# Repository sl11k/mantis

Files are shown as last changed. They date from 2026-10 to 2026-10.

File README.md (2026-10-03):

# MANTIS

**Multimodal Autonomous Non-Invasive Technical Inspection System.** MANTIS is a portable device that
sticks to a machine with magnets. It measures vibration, sound and temperature without touching the
machine's internals, and streams the results live to a phone or computer over Bluetooth LE.

**Live dashboard:** https://sl11k.github.io/mantis/

<p>
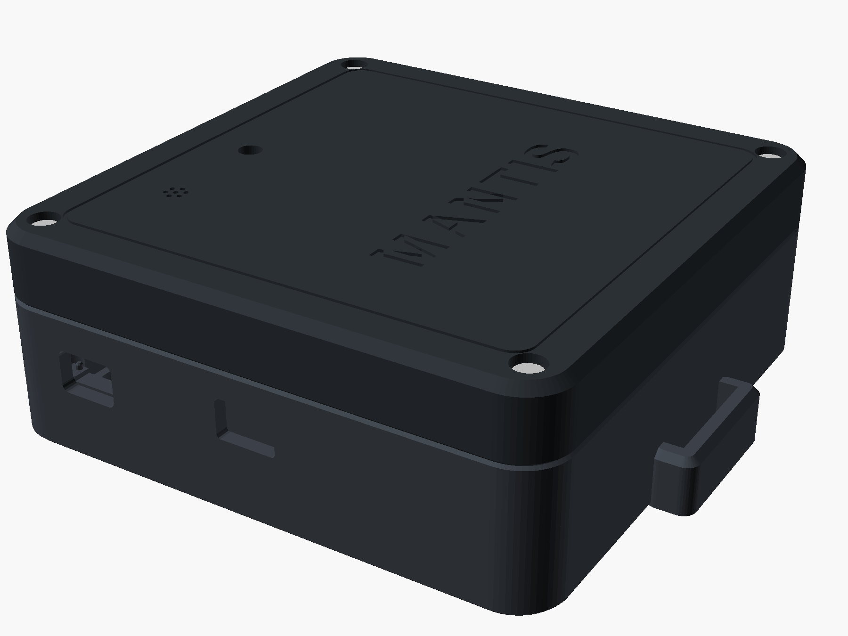
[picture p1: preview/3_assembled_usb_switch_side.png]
Assembled enclosure, USB and switch side
  
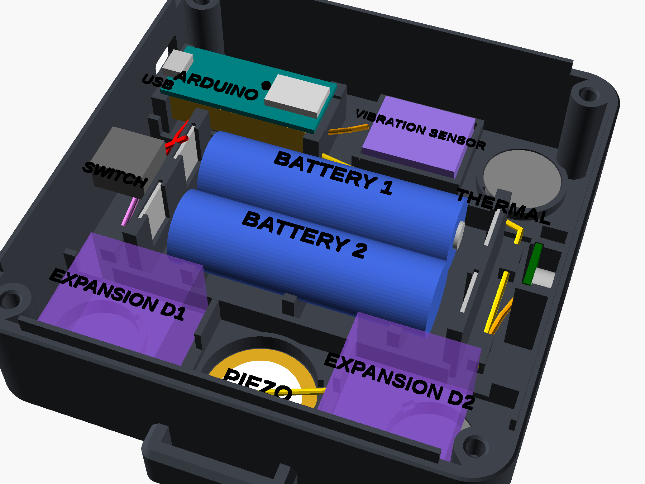
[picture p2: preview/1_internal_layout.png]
Internal layout: Arduino, 2x18650 cells, piezo, IR and vibration sensor bays
  
</p>

| Folder | Contents |
|---|---|
| [`app/`](app/) | Web dashboard (Web Bluetooth / Web Serial). It is deployed to GitHub Pages on every push |
| [`firmware/MANTIS/`](firmware/MANTIS/) | Arduino firmware |
| [`mantis_enclosure.scad`](mantis_enclosure.scad) | Parametric OpenSCAD enclosure (FDM) |
| [`stl/`](stl/) | Ready-to-print top and bottom shells |
| [`preview/`](preview/) | Renders: internal layout, exploded view, sides, machine face, section |

## What it measures

Every ~1.1 s:

- **Vibration.** The LSM9DS1 accelerometer samples at ~930 Hz and each axis gets a 1024-point FFT. From that the device reports:
  - velocity RMS over 10–475 Hz, with the **ISO 10816** zone (A good, B acceptable, C needs attention, D danger) for machine classes I–IV
  - acceleration RMS and peak
  - the dominant frequency
  - a 64-band velocity spectrum
- **Sound.** A-weighted sound level in dB(A) from the on-board PDM microphone. The calibration comes from the datasheets and is approximate (±3 dB); `MIC_CAL_DB` trims it against a reference meter.
- **Inside the enclosure.** Temperature and humidity (HTS221) and pressure (LPS22HB).
- **Surface temperature** (optional). An MLX90614 IR thermometer looks through the side window and is detected automatically when plugged in.
- **Contact / impacts** (optional). A piezo disc on the machine face.

## Hardware

| Part | Notes |
|---|---|
| Arduino Nano 33 BLE Sense **Rev1** | IMU, environmental sensors, microphone and BLE on board |
| MLX90614 / GY-906 IR module (optional) | I²C on A4 (SDA) / A5 (SCL), address 0x5A |
| Piezo disc, 27 mm (optional) | Analog input A0. Set `PIEZO_ENABLED = true` in the firmware |
| 2 × 18650 cells + spring/plate contacts | 2S into VIN through the power switch |
| KCD11 mini rocker (13 × 8.5 mm) or small slide switch | Left wall |
| 4 × Ø20 × 5 mm magnets | Glued into pockets from the inside, 0.8 mm skin to the machine face |
| 4 × M3 × 16 screws + M3 heat-set inserts | Or self-tapping: set `boss_hole_diameter = 2.5` |
| 5 mm LED or light pipe, Ø10 mm rubber pads, 25 mm hook-and-loop strap | Optional |

## Firmware

1. Install the Arduino IDE. In Boards Manager, add **Arduino Mbed OS Nano Boards** (tested with 4.6.0). In Library Manager, add **ArduinoBLE** (tested with 2.1.0). `PDM` and `Wire` come with the board package.
2. Open `firmware/MANTIS/MANTIS.ino`, choose **Arduino Nano 33 BLE** and the board's port, then upload.
3. Settings are at the top of the file: `PIEZO_ENABLED`, `PIEZO_PIN`, `PIEZO_IMPACT_MV`, the default `isoClass`, and `MIC_CAL_DB`.

Outputs:

- **BLE:** advertises as `MANTIS`, service `4d414e54-4953-4e53-5045-435400000000`. The full packet layout is documented in the header of `MANTIS.ino`.
- **USB serial (115200):** one JSON line per measurement window. Lines starting with `#` are human-readable.
- **Commands:** over USB, `C1`…`C4` set the ISO class, `I` blinks the LED, and `M` dumps 4096 raw microphone samples for diagnostics. The same commands go over BLE through the control characteristic.
- **On-board LED:** shows the zone colour. It blinks while waiting for a connection and stays solid once connected. Blue means no data yet.

## Enclosure

The enclosure is 120 × 120 × 45 mm and split at 30 mm. It is fully parametric. Open the file in
OpenSCAD and set `view_mode` to `"bottom"` or `"top"`, then press F6 and export to STL. The `stl/` folder
already contains both shells at the default settings. Assert checks at the end of the file catch parts
that would collide.

The board dimensions in the file come from the Nano 33 BLE Sense **Rev2** datasheet. Rev1 has the same
footprint and mounting holes, but check the microphone port position (`mic_from_usb_end`) against your
board before printing the lid.

## Dashboard

Open https://sl11k.github.io/mantis/ in Chrome or Edge (desktop or Android), or in Bluefy on iPhone.
Then press **Connect Bluetooth** and pick **MANTIS**. It can be added to the home screen and works
offline after the first visit. For USB or local development, run `node app/serve.js` and open
http://localhost:8765. See [`app/README.md`](app/README.md).

Beyond the live view it is an inspection log: add each machine (name, location, ISO class, RPM),
record a steady 10–30 s measurement for it, and the app compares every measurement against that
machine's baseline, flags rises of 25 % or more, gives spectrum-based fault hints, and prints a PDF
report per machine or for the whole route. Data stays on the device; back it up from the Device tab.

After live data arrives, press **Create first reading** to save the next real measurement on this
browser. The completion summary remains after a page reload. Demo data cannot create it.

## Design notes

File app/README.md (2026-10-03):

# MANTIS dashboard

Inspection app for the MANTIS machine-inspection device (Arduino Nano 33 BLE Sense).
It shows vibration severity per ISO 10816 (zones A–D), the dominant frequency and the spectrum,
plus surface and internal temperature, humidity, pressure and sound level. The data arrives over
Bluetooth LE, or over USB on a computer.

Four sections (bottom bar on a phone, tabs on a computer):

| Section | What it does |
|---|---|
| **مباشر / Live** | Machine condition, the live sensor tiles, and **Record measurement**: pick the machine, hold the device on it, and a 10/15/30 s steady average is saved to that machine's log |
| **التحليل / Analysis** | Spectrum with 1×/2×/3× running-speed and 2× mains markers, rule-based fault hints (unbalance, misalignment, looseness, electrical, bearings), and the velocity trend |
| **المعدات / Machines** | Machine list sorted worst first, today's route progress, per-machine history against its baseline (first measurement, or any one you pick), PDF report and share |
| **الجهاز / Device** | Connection, device info, alerts, settings (language, theme, measurement length, 50/60 Hz mains, keep screen on, vibrate/sound alerts) and data backup |

Measurements stay in the browser on that phone or computer. Use **Device → Backup** now and then;
**Restore** merges a backup back in. Reports open the print dialog: choose *Save as PDF* to keep or send one.

**Open it:** https://sl11k.github.io/mantis/

| Device | How |
|---|---|
| Android | Chrome → **اتصال بلوتوث / Connect Bluetooth** → pick **MANTIS** |
| Windows / Mac / Linux | Chrome or Edge, same as above (USB also works) |
| iPhone / iPad | Safari has no Web Bluetooth, so open the link in the **Bluefy** browser (App Store) |

- **Install like an app:** browser menu → *Add to Home screen*. After the first visit it opens offline too.
- **No device at hand?** Press **عرض تجريبي / Demo** to see the dashboard with simulated data (demo measurements are tagged as such).
- **Run locally** (USB development): `node serve.js`, then open http://localhost:8765, or double-click `MANTIS.bat` on Windows.

Single static page, no build step and no dependencies. Arabic (RTL) by default, with English and dark mode.

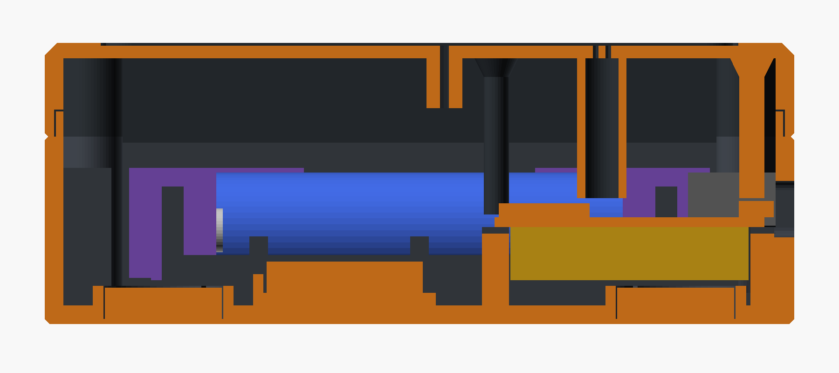
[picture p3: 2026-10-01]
preview/6_section_through_arduino.png

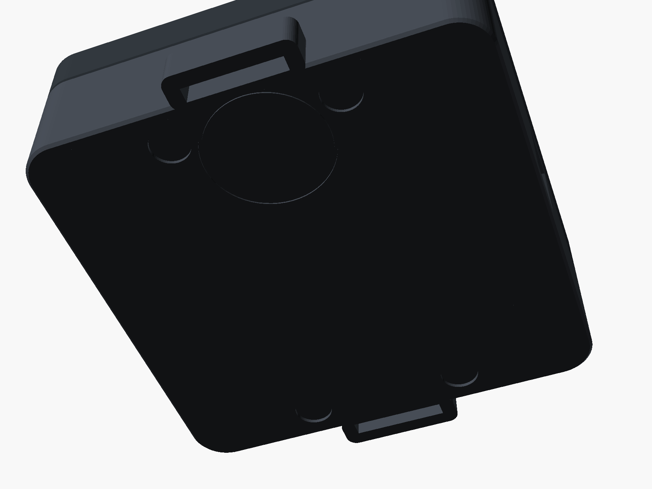
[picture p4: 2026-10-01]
preview/5_bottom_machine_face.png

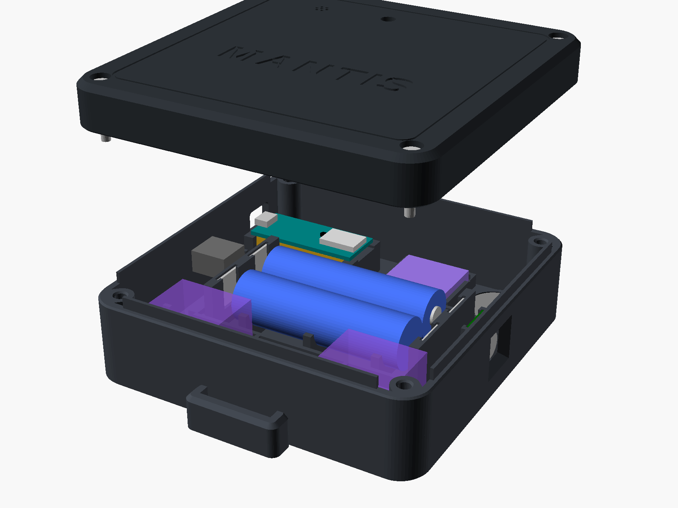
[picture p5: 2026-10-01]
preview/2_exploded.png

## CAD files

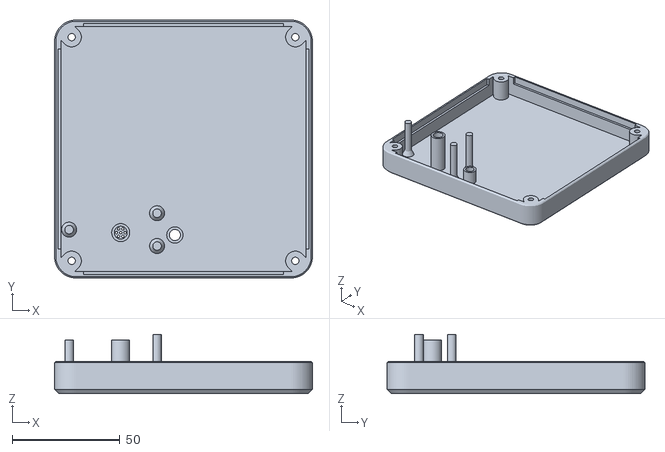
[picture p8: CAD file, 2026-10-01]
stl/MANTIS_top_shell.stl
120.0 x 120.0 x 27.5

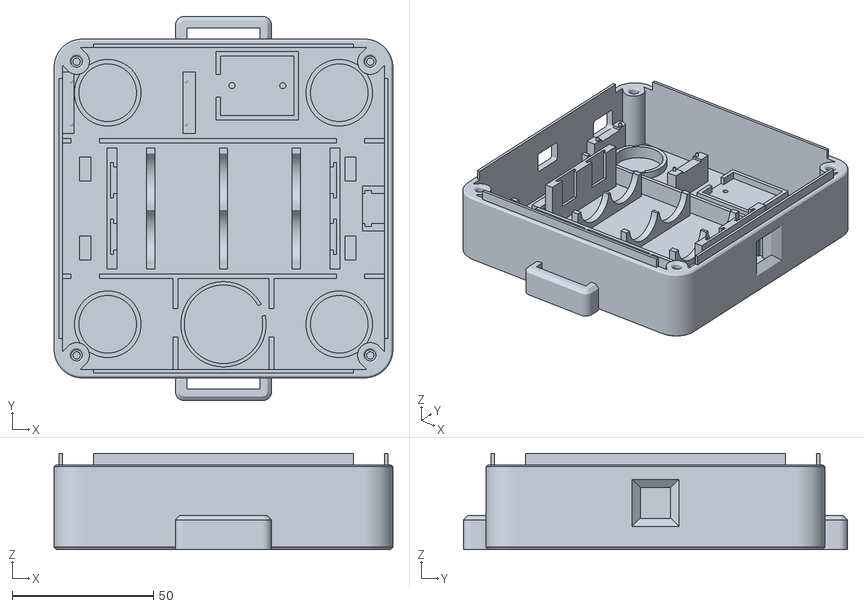
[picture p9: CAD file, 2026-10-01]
stl/MANTIS_bottom_shell.stl
120.0 x 136.0 x 34.0

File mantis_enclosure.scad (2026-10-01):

// ============================================================================
//  MANTIS - Multimodal Autonomous Non-Invasive Technical Inspection System
//  Portable inspection device  |  PARAMETRIC PROTOTYPE ENCLOSURE (FDM)
//  File: mantis_enclosure.scad          Rev B  2026-10-01
// ----------------------------------------------------------------------------
//  HOW TO USE
//    1. Set view_mode below (or use Window > Customizer).
//    2. view_mode = "bottom"  -> F6 -> File > Export > Export as STL
//       view_mode = "top"     -> F6 -> File > Export > Export as STL
//    3. Placeholders, labels and wire paths are NEVER generated in the
//       "top" / "bottom" modes, so they can never end up in a printed STL.
//
//  COORDINATES (assembled)          Z = 0 is the machine-contact face
//    -X = LEFT  wall  : USB access + power switch
//    +X = RIGHT wall  : IR thermal sensor window
//    -Y = FRONT wall,  +Y = BACK wall  (strap lugs on both)
//
//  ZONES (top view)
//    +Y  [ A: ARDUINO  (USB->left wall) ][ C2: VIBRATION POCKET ]
//        [ gutter |  B: 2 x 18650 POWER (along X) | gutter+C3 IR ]
//    -Y  [ D1: EXPANSION ][ C1: PIEZO (floor) ][ D2: EXPANSION ]
//  All dimensions in mm.
// ============================================================================

/* [View] */
// What to show / export
view_mode = "assembled"; // [assembled, top, bottom, exploded, internal_layout, section]
// "top" mode: flip the top shell roof-down (ready-to-print orientation)
print_orientation = true;
// Placeholder parts in assembled / exploded / section views
show_components = true;
show_labels = true;
show_wire_paths = true;
show_screws = true;
// Transparent ghost of the lid in internal_layout view
show_lid_ghost = false;
explode_gap = 45;
// Y position of the cut plane in "section" view (37.5 = through the Arduino)
section_y = 37.5;

/* [Enclosure] */
enclosure_width  = 120; // X  (100 is too small - see FIT CHECK at the end)
enclosure_length = 120; // Y
enclosure_height = 45;  // Z
wall_thickness   = 3.0;
floor_thickness  = 3.0;
roof_thickness   = 2.5;
corner_radius    = 10;
// Parting line height = bottom shell height (top shell = rest)
split_height     = 30;
top_edge_chamfer    = 2.0;
bottom_edge_chamfer = 0.8;
seam_chamfer        = 0.6;

/* [Tolerances] */
tolerance         = 0.4;  // general fit clearance
lip_clearance     = 0.25; // tongue -> lid rebate
battery_clearance = 0.5;  // added to the cell diameter
pcb_clearance     = 0.75; // keep-out around the Arduino PCB (each side)

/* [Shell joint and screws] */
lip_height    = 4;
lip_thickness = 1.2;              // lid keeps wall - lip - clearance = 1.55 mm
screw_diameter = 3;              // M3 (M2.5 possible: scale the values below)
screw_clearance_diameter = 3.4;
screw_head_diameter = 6.5;       // counterbore (M3 socket head = 5.5)
screw_head_depth = 4.5;          // counterbore depth -> M3 x 16 screws
screw_inset = 8;                 // screw axis distance from outer side faces
boss_diameter = 9;
// 4.0 = M3 heat-set insert (OD 4.2-4.6, L 5.7) | 2.5 = direct self-tapping M3
boss_hole_diameter = 4.0;
boss_hole_depth = 7;

/* [Magnets] */
magnet_diameter  = 20;
magnet_thickness = 5;
magnet_clearance = 0.4;  // on diameter - glue gap
magnet_skin      = 0.8;  // plastic between magnet and machine (4 layers @ 0.2)
magnet_cup_wall  = 1.6;
magnet_inset     = 19;   // magnet centre distance from outer side faces

/* [Battery] */
battery_option = "18650_cradle"; // [18650_cradle, pack_bay]
battery_diameter  = 18.5;
battery_length    = 65;
battery_end_space = 5;    // per end: spring / plate contact, protected cells
battery_divider   = 1.0;  // web between the two cells
battery_floor_gap = 2.5;  // under the cells: a hook-and-loop strap passes here
battery_end_wall  = 3.5;
saddle_thickness  = 3;
contact_plate_width = 12.5;
contact_plate_thickness = 1.2;
battery_center = [0, 0];
// Option B: compact Li-ion/LiPo pack or a commercial 2x18650 holder
pack_width  = 42;  // Y
pack_length = 78;  // X
pack_height = 22;

/* [Arduino Nano 33 BLE Sense Rev2] */
arduino_length = 43.16;          // datasheet ABX00069
arduino_width  = 17.76;
arduino_height = 3.0;            // tallest top-side part (USB receptacle)
arduino_pcb_thickness = 1.6;
arduino_hole_spacing_x = 40.64;  // 4 x d1.65 holes, 1.26 from the edges
arduino_hole_spacing_y = 15.24;
arduino_hole_diameter  = 1.65;
// floor -> PCB underside: pins-down headers (8.5) clear the magnet cup
arduino_standoff = 12.5;
arduino_center_y = 37.5;         // back edge clears the corner screw boss
arduino_usb_overhang = 1.5;      // micro-USB receptacle sticks out past the PCB
arduino_wall_gap = 0.3;          // USB receptacle face -> inner wall
arduino_peg_diameter = 1.4;      // locating pegs into the PCB holes (0 = none)
arduino_holddown = true;         // lid posts clamp the board when closed
holddown_gap = 0.4;
// MP34DT06 microphone port: from the USB-end PCB edge / from PCB centre line
mic_from_usb_end = 26.0;
mic_offset_y = 1.4;

/* [Openings] */
usb_width  = 13;   // Y - generous for any micro-USB / USB-C over-mould
usb_height = 9;    // Z
usb_connector_height = 2.6;
// 13 x 8.5 = KCD11 mini rocker | 9 x 4 = small slide switch
switch_width  = 13;   // Y
switch_height = 8.5;  // Z
switch_depth  = 14;   // body depth behind the wall (keep-out)
switch_y = 0;
switch_z = 20;
led_diameter = 5.2;          // 5 mm LED or light pipe
led_position = [-4, 40];
led_tube_length = 8;
mic_hole_diameter = 1.2;
mic_hole_pitch = 2.0;
mic_grille_diameter = 6;
mic_duct = true;             // acoustic duct from the grille down to the mic
mic_duct_inner_diameter = 6;
mic_duct_gap = 3;            // duct end above the PCB top (add a foam ring)

/* [Piezo / contact sensor] */
piezo_shape  = "round"; // [round, rect]
piezo_width  = 27;   // disc diameter (round) or X size (rect)
piezo_length = 27;   // Y size (rect only)
piezo_height = 0.6;  // element thickness (placeholder)
piezo_clearance = 0.8;
// floor left under the element; 0 = through-hole + ledge (direct-contact puck)
piezo_skin = 1.0;
piezo_ledge = 1.5;
piezo_center = [0, -41];
piezo_ring = true;   // low ring that locates a foam backing pad / weight

/* [IR thermal sensor] */
thermal_sensor_width  = 12;   // along the wall (Y) - e.g. GY-906 / MLX90614
thermal_sensor_length = 17;   // vertical (Z)
thermal_sensor_height = 6.5;  // depth from the wall incl. sensor can (X)
thermal_pcb_thickness = 1.6;
thermal_can_diameter  = 9.2;  // TO-39 can
thermal_fov = 90;             // full field of view -> window flare
thermal_y = 0;
thermal_base_z = 8;           // module bottom edge height

/* [External vibration sensor] */
vibration_sensor_width  = 25; // X
vibration_sensor_length = 20; // Y
vibration_sensor_height = 5;  // Z
vibration_center = [12, 43.5];
vibration_pad_height = 2;
vibration_fence_height = 3;
vibration_hole_diameter = 2.2; // M2.5 self-tapping pilot
vibration_hole_spacing = 18;

/* [Expansion] */
expansion_width  = 28;  // X
expansion_length = 29;  // Y
expansion_height = 18;  // Z
expansion_center = [-32.5, -40.5];  // D1; D2 is the mirror image (+X)
expansion_floor_z = 7;              // reserved volume starts above the magnet cup
expansion_second_bay = true;

/* [Internal ribs and cable routing] */
rib_thickness = 1.6;
rib_height = 8;
rib_back_y  = 24;
rib_front_y = -24;
rib_divider_x = 17;          // dividers at +/- this X in the front band
rib_notch_width = 10;
rib_notch_depth = 6;
back_rib_notches  = [-49, 45];
front_rib_notches = [-49, 45];
cable_anchor_positions = [[-49, 14], [-49, -14], [45, 14], [45, -14]];

/* [Bottom face] */
rubber_pads = true;
pad_diameter = 10;
pad_recess = 1.0;
pad_positions = [[-22, -50], [22, -50], [-22, 50], [22, 50]];
strap_slots = true;
strap_width = 26;          // slot length (25 mm hook-and-loop strap)
strap_slot_thickness = 4;
strap_lug_depth = 8;
strap_lug_height = 12;
bottom_markings = true;

/* [Top panel] */
logo_text = "MANTIS";
logo_size = 11;
logo_depth = 0.6;
logo_position = [0, -14];
panel_groove = true;
panel_inset = 9;

/* [Hidden] */
$fa = 6;
$fs = 0.5;
EPS = 0.01;

// ============================================================================
//  DERIVED VALUES
// ============================================================================
W = enclosure_width;  L = enclosure_length;  H = enclosure_height;
R = corner_radius;
IX = W/2 - wall_thickness;           // interior half sizes
IY = L/2 - wall_thickness;
RI = max(0.5, R - wall_thickness);   // interior corner radius
FZ = floor_thickness;                // inner floor plane
HB = split_height;                   // parting line
HT = H - split_height;               // top shell height
ROOF_Z = H - roof_thickness;         // inner roof plane
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

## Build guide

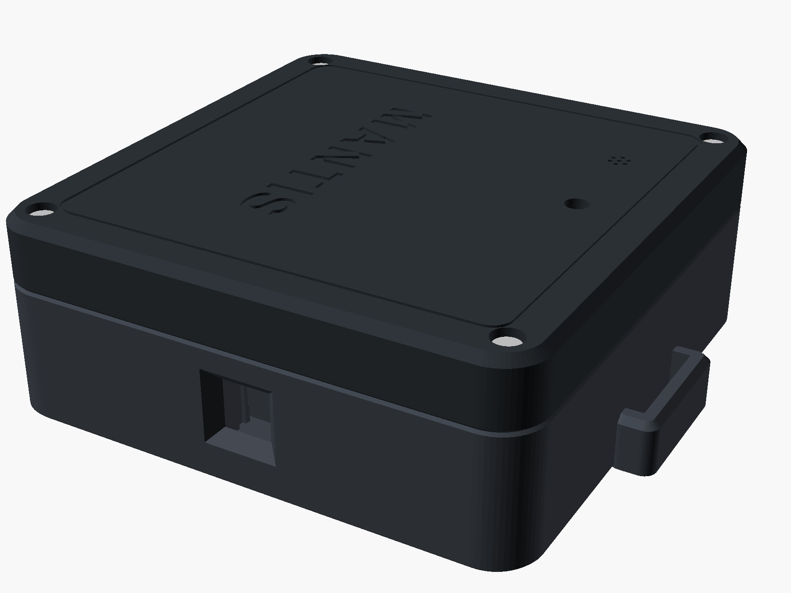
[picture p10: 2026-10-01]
preview/4_assembled_ir_side.png

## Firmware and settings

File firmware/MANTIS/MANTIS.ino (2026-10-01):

// ============================================================================
//  MANTIS - Multimodal Autonomous Non-Invasive Technical Inspection System
//  Firmware for Arduino Nano 33 BLE Sense Rev1 (nRF52840)            v1.1.1
// ----------------------------------------------------------------------------
//  Every analysis window (1024 accelerometer samples, ~1.08 s) the device
//  measures and publishes:
//    vibration  LSM9DS1 accelerometer @ 952 Hz, 1024-point FFT per axis:
//               velocity RMS 10-475 Hz (mm/s) + ISO 10816 zone, acceleration
//               RMS / peak, dominant frequency, 64-band velocity spectrum
//    acoustic   MP34DT05 PDM microphone, A-weighted sound level dB(A) (approx.)
//    internal   HTS221 temperature / humidity, LPS22HB pressure
//    surface    MLX90614 IR thermometer on A4/A5 (optional, hot-plug)
//    contact    piezo disc on an analog pin (optional, see PIEZO_ENABLED)
//
//  Outputs
//    BLE  service 4d414e54-4953-4e53-5045-435400000000 (see BLE PROTOCOL)
//    USB  one JSON line per window @ 115200 baud; lines starting with '#'
//         are human-readable. Commands: "C1".."C4" (ISO class), "I" (identify),
//         "M" (dump 4096 raw microphone samples as "#R" lines, for diagnostics)
//  Libraries: ArduinoBLE (Library Manager); PDM and Wire come with the core.
//
//  BLE PROTOCOL (all little-endian; 0x7FFF / 0xFFFF = not available)
//   ...0001 vibration    read/notify 20 B
//      u16 seq | u16 vel_rms 0.01 mm/s | u16 acc_rms mg | u16 acc_peak mg |
//      u16 dom_freq 0.1 Hz | u16 dom_vel 0.01 mm/s | u16 piezo_peak mV |
//      u16 piezo_rms mV | u16 piezo_impacts | u8 zone 1-4 = A-D (0 = none) |
//      u8 flags (bit0 FIFO overrun, bits1-2 axis 0=X 1=Y 2=Z)
//   ...0002 environment  read/notify 20 B
//      u16 seq | i16 temp 0.01 C | u16 humidity 0.01 % | u16 pressure 0.1 hPa |
//      i16 ir_object 0.01 C | i16 ir_ambient 0.01 C | i16 sound 0.1 dB(A) |
//      u32 uptime s | u8 sensors (bit0 HTS221, 1 LPS22HB, 2 IMU, 3 MIC,
//      4 MLX90614, 5 PIEZO) | u8 iso_class 1-4
//   ...0003 spectrum     notify, 4 chunks x 20 B per window
//      u8 seq & 0xFF | u8 chunk 0-3 | u16 fs 0.1 Hz | 16 x u8 band
//      band b (0-63) = velocity RMS over FFT bins K0 + 7b .. K0 + 7b + 6,
//      encoded 40 * log10(v / 0.001 mm/s), 0 = below 1 um/s
//   ...0004 control      write: [1, class 1-4] ISO 10816 class, [2] identify
//   ...0005 info         read: "fw=..;board=..;n=1024;k0=11;bw=7"
// ============================================================================

#include <ArduinoBLE.h>
#include <PDM.h>
#include <Wire.h>
#include <mbed.h>
using namespace std::chrono_literals;

#define FW_VERSION "1.1.1"

// ---------------------------------------------------------------- settings --
const bool  PIEZO_ENABLED   = false;  // set to true once the piezo disc is wired
const int   PIEZO_PIN       = A0;
const float PIEZO_IMPACT_MV = 300;    // impact = rising edge above this level
uint8_t isoClass = 2;                 // ISO 10816 machine class 1-4

// ISO 10816-1 zone limits A/B, B/C, C/D in mm/s RMS
const float ISO_LIMITS[4][3] = {
  {0.71f, 1.8f, 4.5f},    // I   small machines (< 15 kW)
  {1.12f, 2.8f, 7.1f},    // II  medium machines (15-75 kW)
  {1.8f,  4.5f, 11.2f},   // III large machines, rigid foundation
  {2.8f,  7.1f, 18.0f},   // IV  large machines, flexible foundation
};

// ------------------------------------------------------------- I2C devices --
const uint8_t ADDR_LPS22HB  = 0x5C;   // internal bus (Wire1)
const uint8_t ADDR_HTS221   = 0x5F;
const uint8_t ADDR_LSM9DS1  = 0x6B;
const uint8_t ADDR_MLX90614 = 0x5A;   // external bus (Wire, A4/A5)

bool hasHTS = false, hasLPS = false, hasIMU = false, hasMic = false, hasMLX = false;
bool bleOk = false;

// ------------------------------------------------------- vibration analysis --
const int   FFT_N   = 1024;           // samples per window (power of 2)
const int   K0      = 11;             // first FFT bin used (~10 Hz)
const int   BANDS   = 64;
const int   BAND_W  = 7;              // FFT bins per spectrum band
const float ACC_LSB = 0.122e-3f;      // g per LSB at +/-4 g
const float G0      = 9.80665f;

float bufX[FFT_N], bufY[FFT_N], bufZ[FFT_N];
int   nSamples = 0;
uint32_t overrunCount = 0;

// The accelerometer FIFO (32 samples = 34 ms) is drained by its own thread
// into this ring (1.1 s), so BLE writes or analysis in loop() never lose data
rtos::Thread imuThread(osPriorityAboveNormal, 4096);
rtos::Mutex  wire1Lock;               // Wire1 is shared by the IMU thread and loop()
const int RING_N = 1024;
int16_t ring[RING_N][3];
volatile uint32_t ringHead = 0, ringTail = 0;
volatile bool imuOverrun = false;
float fftRe[FFT_N], fftIm[FFT_N], hann[FFT_N];
float twCos[FFT_N / 2], twSin[FFT_N / 2];
float msv[FFT_N / 2], bestMsv[FFT_N / 2];  // velocity mean square per bin, (mm/s)^2

volatile uint32_t fsSamples = 0, fsStartMs = 0;
float fs = 952.0f;                    // measured accelerometer sample rate

struct {
  float velRms = NAN, accRms = NAN, accPeak = NAN, domFreq = NAN, domVel = NAN;
  uint8_t zone = 0, axis = 0;
  bool overrun = false;
  uint8_t bands[BANDS] = {0};
} vib;

// ------------------------------------------------------------ environment --
struct {
  float temp = NAN, rh = NAN, hPa = NAN, irObj = NAN, irAmb = NAN, sound = NAN;
} env;

float htsT0, htsT1, htsH0, htsH1;
int16_t htsT0out, htsT1out, htsH0out, htsH1out;
uint8_t mlxFails = 0;
uint32_t lastMlxProbe = 0;

// ------------------------------------------------------------- microphone --
// Sound level in dB(A). The MP34DT05 output is dominated by sub-60 Hz drift,
// so it goes through an A-weighting filter (two biquads, bilinear at 16 kHz;
// the 12.2 kHz poles are above Nyquist and omitted) before the RMS.
// Calibration from datasheets: MP34DT05 -26 dBFS @ 94 dB SPL, nRF52840 PDM
// module gain +3.2 dB ("2500 RMS"), Arduino PDM default gain setting -10 dB:
// 94 dB SPL -> -32.35 dBFS, so dB SPL = dBFS + 126.35. Typical accuracy of an
// uncalibrated MEMS mic is +/-3 dB; MIC_CAL_DB trims it against a reference meter.
const float MIC_FS     = 16000.0f;
const float MIC_REF_DB = 126.35f;
const float MIC_CAL_DB = 0.0f;
short micBuf[256];
volatile float micSumSq = 0;
volatile uint32_t micCount = 0;
uint32_t micSettle = 8000;            // skip the filter start-up (0.5 s)
struct Biquad { float b0, b1, b2, a1, a2, z1, z2; };
Biquad aw[2];
float awGain = 1;

// raw capture for diagnostics (USB command "M"): 4096 samples = 256 ms
const int RAW_N = 4096;
int16_t rawMic[RAW_N];
volatile int rawFill = -1;            // -1 idle, 0..RAW_N-1 filling, RAW_N ready

// ------------------------------------------------------------------ piezo --
float pzPeak = 0, pzSumSq = 0;
uint32_t pzCount = 0, pzImpacts = 0;
bool pzArmed = true;
float pzPeakOut = NAN, pzRmsOut = NAN;
uint32_t pzImpactsOut = 0;

// -------------------------------------------------------------------- BLE --
#define MANTIS_UUID(x) "4d414e54-4953-4e53-5045-43540000" x
BLEService        mantisService(MANTIS_UUID("0000"));
BLECharacteristic vibChar (MANTIS_UUID("0001"), BLERead | BLENotify, 20, true);
BLECharacteristic envChar (MANTIS_UUID("0002"), BLERead | BLENotify, 20, true);
BLECharacteristic specChar(MANTIS_UUID("0003"), BLENotify, 20, true);
BLECharacteristic ctrlChar(MANTIS_UUID("0004"), BLEWrite | BLEWriteWithoutResponse, 4, false);
BLEStringCharacteristic infoChar(MANTIS_UUID("0005"), BLERead, 96);

// Notifications go out one per loop pass: a write can wait for a free
// controller buffer, and a burst of six would stall the accelerometer FIFO
uint8_t txVib[20], txEnv[20], txSpec[4][20];
int8_t  txNext = -1;                  // -1 idle, 0 vib, 1 env, 2-5 spectrum chunks

uint16_t seq = 0;
uint32_t identifyUntil = 0;
uint32_t procMs = 0;

// ============================================================ I2C helpers ===
bool probe(TwoWire &bus, uint8_t addr) {
  bus.beginTransmission(addr);
  return bus.endTransmission() == 0;
}

bool writeReg(TwoWire &bus, uint8_t addr, uint8_t reg, uint8_t val) {
  bus.beginTransmission(addr);
  bus.write(reg);
  bus.write(val);
  return bus.endTransmission() == 0;
}

bool readRegs(TwoWire &bus, uint8_t addr, uint8_t reg, uint8_t *buf, uint8_t n) {
  bus.beginTransmission(addr);
  bus.write(reg);
  if (bus.endTransmission(false) != 0) return false;
  if (bus.requestFrom(addr, n) != n) return false;
  for (uint8_t i = 0; i < n; i++) buf[i] = bus.read();
  return true;
}

// ================================================================ sensors ===
bool initIMU() {
  if (!writeReg(Wire1, ADDR_LSM9DS1, 0x22, 0x05)) return false;  // CTRL_REG8: soft reset
  delay(10);
  writeReg(Wire1, ADDR_LSM9DS1, 0x22, 0x44);  // block data update + auto-increment
  writeReg(Wire1, ADDR_LSM9DS1, 0x10, 0x00);  // gyro off -> accelerometer-only FIFO
  writeReg(Wire1, ADDR_LSM9DS1, 0x20, 0xD0);  // CTRL_REG6_XL: 952 Hz, +/-4 g, BW 408 Hz
  writeReg(Wire1, ADDR_LSM9DS1, 0x23, 0x02);  // CTRL_REG9: FIFO enable
  writeReg(Wire1, ADDR_LSM9DS1, 0x2E, 0x00);  // FIFO bypass (clears it)
  return writeReg(Wire1, ADDR_LSM9DS1, 0x2E, 0xC0);  // FIFO continuous mode
}

// IMU thread: drain the FIFO every 10 ms in one burst. In FIFO mode the
// register address wraps from OUT_Z_H_XL (0x2D) back to OUT_X_L_XL (0x28),
// so n samples are read as one 6*n byte transfer.
void imuTask() {
  static uint8_t b[32 * 6];
  while (true) {
    wire1Lock.lock();
    uint8_t src = 0;
    int n = 0;
    if (readRegs(Wire1, ADDR_LSM9DS1, 0x2F, &src, 1)) {
      n = src & 0x3F;
      if (n > 0 && !readRegs(Wire1, ADDR_LSM9DS1, 0x28, b, n * 6)) n = 0;
    }
    wire1Lock.unlock();
    if (src & 0x40) imuOverrun = true;
    for (int i = 0; i < n; i++) {
      uint32_t next = (ringHead + 1) % RING_N;
      if (next == ringTail) {
        imuOverrun = true;
        break;
      }
      const uint8_t *s = b + i * 6;
      ring[ringHead][0] = (int16_t)(s[1] << 8 | s[0]);
      ring[ringHead][1] = (int16_t)(s[3] << 8 | s[2]);
      ring[ringHead][2] = (int16_t)(s[5] << 8 | s[4]);
      ringHead = next;
    }
    if (n > 0) {  // sample-rate clock starts at the first batch
      if (fsStartMs == 0) fsStartMs = millis();
      else fsSamples += n;
    }
    rtos::ThisThread::sleep_for(10ms);
  }
}

// loop(): move samples from the ring into the analysis window
void pollIMU() {
  while (nSamples < FFT_N && ringTail != ringHead) {
    bufX[nSamples] = ring[ringTail][0] * ACC_LSB;
    bufY[nSamples] = ring[ringTail][1] * ACC_LSB;
    bufZ[nSamples] = ring[ringTail][2] * ACC_LSB;
    nSamples++;
    ringTail = (ringTail + 1) % RING_N;
  }
}

bool initHTS221() {
  uint8_t c[16];
  if (!readRegs(Wire1, ADDR_HTS221, 0x30 | 0x80, c, 16)) return false;  // 0x80 = auto-increment
  htsH0 = c[0] / 2.0f;
  htsH1 = c[1] / 2.0f;
  htsT0 = (((uint16_t)(c[5] & 0x03) << 8) | c[2]) / 8.0f;
  htsT1 = (((uint16_t)(c[5] & 0x0C) << 6) | c[3]) / 8.0f;
  htsH0out = (int16_t)(c[7]  << 8 | c[6]);
  htsH1out = (int16_t)(c[11] << 8 | c[10]);
  htsT0out = (int16_t)(c[13] << 8 | c[12]);
  htsT1out = (int16_t)(c[15] << 8 | c[14]);
  return writeReg(Wire1, ADDR_HTS221, 0x20, 0x85);  // power on, BDU, 1 Hz continuous
}

void readHTS221() {
  uint8_t b[4];
  if (!readRegs(Wire1, ADDR_HTS221, 0x28 | 0x80, b, 4)) return;
  int16_t hOut = (int16_t)(b[1] << 8 | b[0]);
  int16_t tOut = (int16_t)(b[3] << 8 | b[2]);
  env.temp = htsT0 + (tOut - htsT0out) * (htsT1 - htsT0) / (float)(htsT1out - htsT0out);
  env.rh = constrain(htsH0 + (hOut - htsH0out) * (htsH1 - htsH0) / (float)(htsH1out - htsH0out), 0.0f, 100.0f);
}

bool initLPS22HB() {
  if (!writeReg(Wire1, ADDR_LPS22HB, 0x11, 0x10)) return false;  // CTRL_REG2: auto-increment
  return writeReg(Wire1, ADDR_LPS22HB, 0x10, 0x12);              // CTRL_REG1: 1 Hz, BDU
}

void readLPS22HB() {
  uint8_t b[3];
  if (!readRegs(Wire1, ADDR_LPS22HB, 0x28, b, 3)) return;
  env.hPa = (((int32_t)b[2] << 16) | ((int32_t)b[1] << 8) | b[0]) / 4096.0f;
}

// MLX90614 RAM register (0x06 = ambient, 0x07 = object)
bool readMLX(uint8_t reg, float &tempC) {
  uint8_t b[3];
  if (!readRegs(Wire, ADDR_MLX90614, reg, b, 3)) return false;
  uint16_t raw = b[0] | (uint16_t)b[1] << 8;  // b[2] = PEC
  if (raw & 0x8000) return false;             // error flag
  tempC = raw * 0.02f - 273.15f;
  return true;
}

void readMLX90614() {
  if (!hasMLX) {  // hot-plug: look for it every 5 s
    if (millis() - lastMlxProbe < 5000) return;
    lastMlxProbe = millis();
    if (!probe(Wire, ADDR_MLX90614)) return;
    hasMLX = true;
    mlxFails = 0;
  }
  float o, a;
  if (readMLX(0x07, o) && readMLX(0x06, a)) {
    env.irObj = o;
    env.irAmb = a;
    mlxFails = 0;
  } else if (++mlxFails >= 3) {
    hasMLX = false;
    env.irObj = env.irAmb = NAN;
  }
}

// Analog high-pass section s^2 / (s^2 + a1 s + a0) -> digital biquad (bilinear)
// (computed in double once: the 20 Hz poles sit at r = 0.992, close to z = 1)
Biquad bilinearHP(double a1, double a0) {
  const double K = 2.0 * MIC_FS, d = K * K + a1 * K + a0;
  return { (float)(K * K / d), (float)(-2 * K * K / d), (float)(K * K / d),
           (float)((2 * a0 - 2 * K * K) / d), (float)((K * K - a1 * K + a0) / d), 0, 0 };
}

float biquadGainAt(const Biquad &q, float f) {
  float w = 2 * PI * f / MIC_FS, c1 = cosf(w), s1 = sinf(w), c2 = cosf(2 * w), s2 = sinf(2 * w);
  float nr = q.b0 + q.b1 * c1 + q.b2 * c2, ni = -(q.b1 * s1 + q.b2 * s2);
  float dr = 1 + q.a1 * c1 + q.a2 * c2, di = -(q.a1 * s1 + q.a2 * s2);
  return sqrtf((nr * nr + ni * ni) / (dr * dr + di * di));
}

void initAWeighting() {
  const double w1 = 2 * PI * 20.598997, w2 = 2 * PI * 107.65265, w3 = 2 * PI * 737.86223;
  aw[0] = bilinearHP(2 * w1, w1 * w1);
  aw[1] = bilinearHP(w2 + w3, w2 * w3);
  awGain = 1 / (biquadGainAt(aw[0], 1000) * biquadGainAt(aw[1], 1000));  // 0 dB at 1 kHz
}

inline float biquadRun(Biquad &q, float x) {  // transposed direct form II
  float y = q.b0 * x + q.z1;
  q.z1 = q.b1 * x - q.a1 * y + q.z2;
  q.z2 = q.b2 * x - q.a2 * y;
  return y;
}

// PDM callback (interrupt context): A-weight every sample, accumulate energy
void onPDMdata() {
  int bytes = PDM.available();
  if (bytes > (int)sizeof(micBuf)) bytes = sizeof(micBuf);
  PDM.read(micBuf, bytes);
  int n = bytes / 2;
  if (n <= 0) return;
  if (rawFill >= 0 && rawFill < RAW_N) {
    int k = min(n, RAW_N - rawFill);
    memcpy(rawMic + rawFill, micBuf, k * sizeof(int16_t));
    rawFill += k;
  }
  float s = 0;
  for (int i = 0; i < n; i++) {
    float y = biquadRun(aw[1], biquadRun(aw[0], micBuf[i])) * awGain;
    s += y * y;
  }
  if (micSettle > 0) {
    micSettle = micSettle > (uint32_t)n ? micSettle - n : 0;
    return;
  }
  micSumSq += s;
  micCount += n;
}

void readMic() {
  noInterrupts();
  float s = micSumSq;
  uint32_t n = micCount;
  micSumSq = 0;
  micCount = 0;
  interrupts();
  env.sound = (n > 0 && s > 0) ? 10.0f * log10f(s / n / (32768.0f * 32768.0f)) + MIC_REF_DB + MIC_CAL_DB : NAN;
}

void pollPiezo() {
  if (!PIEZO_ENABLED) return;
  float mv = analogRead(PIEZO_PIN) * (3300.0f / 4095.0f);
  if (mv > pzPeak) pzPeak = mv;
  pzSumSq += mv * mv;
  pzCount++;
  if (pzArmed && mv > PIEZO_IMPACT_MV) {
    pzImpacts++;
    pzArmed = false;
  } else if (mv < PIEZO_IMPACT_MV / 2) {
    pzArmed = true;
  }
}

void takePiezo() {
  if (!PIEZO_ENABLED) return;
  pzPeakOut = pzPeak;
  pzRmsOut = pzCount ? sqrtf(pzSumSq / pzCount) : NAN;
  pzImpactsOut = pzImpacts;
  pzPeak = pzSumSq = 0;
  pzCount = pzImpacts = 0;
}

// =============================================================== analysis ===
void initTables() {
  for (int i = 0; i < FFT_N / 2; i++) {
    twCos[i] = cosf(2 * PI * i / FFT_N);
    twSin[i] = -sinf(2 * PI * i / FFT_N);
  }
  for (int i = 0; i < FFT_N; i++) hann[i] = 0.5f - 0.5f * cosf(2 * PI * i / FFT_N);  // periodic Hann
}

// In-place iterative radix-2 FFT
void fft(float *re, float *im) {
  for (int i = 1, j = 0; i < FFT_N; i++) {
    int bit = FFT_N >> 1;
    for (; j & bit; bit >>= 1) j ^= bit;
    j ^= bit;
    if (i < j) {
      float t = re[i]; re[i] = re[j]; re[j] = t;
      t = im[i]; im[i] = im[j]; im[j] = t;
    }
  }
  for (int len = 2; len <= FFT_N; len <<= 1) {
    int half = len >> 1, step = FFT_N / len;
    for (int i = 0; i < FFT_N; i += len) {
      for (int k = 0; k < half; k++) {
        float wr = twCos[k * step], wi = twSin[k * step];
        int a = i + k, b = a + half;
        float tr = re[b] * wr - im[b] * wi;
        float ti = re[b] * wi + im[b] * wr;
        re[b] = re[a] - tr;
        im[b] = im[a] - ti;
        re[a] += tr;
        im[a] += ti;
      }
    }
  }
}

// Velocity mean square per bin for one axis; returns velocity RMS in mm/s
float analyzeAxis(const float *buf, float mean, float *out) {
  for (int i = 0; i < FFT_N; i++) {
    fftRe[i] = (buf[i] - mean) * G0 * hann[i];  // m/s^2
    fftIm[i] = 0;
  }
  fft(fftRe, fftIm);
  // one-sided mean square per bin, Hann window: sum(w^2) = 3N/8
  const float norm = 2.0f / (FFT_N * (3.0f * FFT_N / 8.0f));
  const float df = fs / FFT_N;
  float sum = 0;
  for (int k = 0; k < FFT_N / 2; k++) {
    if (k < K0) {
      out[k] = 0;
      continue;
    }
    float w = 2 * PI * k * df;
    float v = (fftRe[k] * fftRe[k] + fftIm[k] * fftIm[k]) * norm / (w * w) * 1e6f;  // (mm/s)^2
    out[k] = v;
    sum += v;
  }
  return sqrtf(sum);
}

void processVibration() {
  vib.overrun = imuOverrun;
  if (imuOverrun) overrunCount++;
  imuOverrun = false;

  if (fsSamples > 3000) {
    float measured = fsSamples * 1000.0f / (millis() - fsStartMs);
    if (measured > 850 && measured < 1050) fs = measured;
  }

  float *bufs[3] = {bufX, bufY, bufZ};
  float mean[3];
  for (int a = 0; a < 3; a++) {
    float s = 0;
    for (int i = 0; i < FFT_N; i++) s += bufs[a][i];
    mean[a] = s / FFT_N;
  }
  float sumSq = 0, peak2 = 0;
  for (int i = 0; i < FFT_N; i++) {
    float dx = bufX[i] - mean[0], dy = bufY[i] - mean[1], dz = bufZ[i] - mean[2];
    float d2 = dx * dx + dy * dy + dz * dz;
    sumSq += d2;
    if (d2 > peak2) peak2 = d2;
  }
  vib.accRms = sqrtf(sumSq / FFT_N);
  vib.accPeak = sqrtf(peak2);

  // ISO 10816 uses the direction with the highest reading
  float best = -1;
  for (int a = 0; a < 3; a++) {
    float v = analyzeAxis(bufs[a], mean[a], msv);
    if (v > best) {
      best = v;
      vib.axis = a;
      memcpy(bestMsv, msv, sizeof(msv));
    }
  }
  vib.velRms = best;

  // dominant frequency (parabolic interpolation on magnitude)
  int kMax = K0;
  for (int k = K0 + 1; k < FFT_N / 2; k++)
    if (bestMsv[k] > bestMsv[kMax]) kMax = k;
  float sumLobe = 0;
  for (int k = kMax - 2; k <= kMax + 2; k++)
    if (k >= K0 && k < FFT_N / 2) sumLobe += bestMsv[k];
  vib.domVel = sqrtf(sumLobe);
  float delta = 0;
  if (kMax > K0 && kMax < FFT_N / 2 - 1) {
    float m1 = sqrtf(bestMsv[kMax - 1]), m2 = sqrtf(bestMsv[kMax]), m3 = sqrtf(bestMsv[kMax + 1]);
    float den = m1 - 2 * m2 + m3;
    if (den < 0) delta = constrain(0.5f * (m1 - m3) / den, -0.5f, 0.5f);
  }
  vib.domFreq = (kMax + delta) * fs / FFT_N;

  for (int b = 0; b < BANDS; b++) {
    float s = 0;
    for (int k = K0 + b * BAND_W; k < K0 + (b + 1) * BAND_W; k++) s += bestMsv[k];
    float v = sqrtf(s);
    float code = v > 0.001f ? 40.0f * log10f(v / 0.001f) : 0;
    vib.bands[b] = (uint8_t)constrain(code + 0.5f, 0.0f, 255.0f);
  }

  const float *lim = ISO_LIMITS[isoClass - 1];
  vib.zone = vib.velRms < lim[0] ? 1 : vib.velRms < lim[1] ? 2 : vib.velRms < lim[2] ? 3 : 4;
}

void readEnvironment() {
  wire1Lock.lock();
  if (hasHTS) readHTS221();
  if (hasLPS) readLPS22HB();
  wire1Lock.unlock();
  if (hasMic) readMic();
  readMLX90614();
  takePiezo();
}

// ================================================================ outputs ===
uint16_t u16(float v) {
  if (isnan(v)) return 0xFFFF;
  return (uint16_t)constrain(v + 0.5f, 0.0f, 65534.0f);
}

int16_t i16(float v) {
  if (isnan(v)) return 0x7FFF;
  return (int16_t)lroundf(constrain(v, -32767.0f, 32766.0f));
}

void put16(uint8_t *p, uint16_t v) {
  p[0] = v & 0xFF;
  p[1] = v >> 8;
}

uint8_t sensorMask() {
  return hasHTS | hasLPS << 1 | hasIMU << 2 | hasMic << 3 | hasMLX << 4 | PIEZO_ENABLED << 5;
}
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
void loop() {
  static bool wasConnected = false;
  static uint32_t lastPublish = 0;
  static bool wasBleConnected = false;
  static uint32_t lastAdvertise = 0;

  if (bleOk) {
    BLE.poll();
    const bool isBleConnected = BLE.connected();
    // Some central devices leave the radio undiscoverable after a disconnect.
    // Refresh advertising only while idle; an active connection is untouched.
    if (!isBleConnected && (wasBleConnected || millis() - lastAdvertise >= 15000)) {
      BLE.advertise();
      lastAdvertise = millis();
    }
    wasBleConnected = isBleConnected;
    pollIMU();
    sendPendingBLE();
  }
  pollIMU();
  pollPiezo();
  handleSerial();
  updateLed();

  bool usb = Serial;
  if (usb && !wasConnected) printBanner();
  wasConnected = usb;

  if (rawFill == RAW_N) {  // dump the raw capture, 256 samples per '#R' line
    for (int i = 0; i < RAW_N; i += 256) {
      json = "#R ";
      for (int j = i; j < i + 256; j++) {
        if (j > i) json += ',';
        json += rawMic[j];
      }
      json += "\r\n";
      Serial.write((const uint8_t *)json.c_str(), json.length());
    }
    rawFill = -1;
  }

  // publish once per analysis window (or once a second without an IMU)
  bool windowReady = hasIMU ? nSamples >= FFT_N : millis() - lastPublish >= 1000;
  if (!windowReady) return;

  uint32_t t0 = millis();
  if (hasIMU) {
    processVibration();
    nSamples = 0;
  }
  readEnvironment();
  seq++;
  if (bleOk) publishBLE();
  publishSerial();
  procMs = millis() - t0;
  lastPublish = millis();
}

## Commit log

2026-10-01 Add MANTIS inspection dashboard
    Live web dashboard for the MANTIS device (Arduino Nano 33 BLE Sense):
    ISO 10816 vibration zones, dominant frequency, velocity spectrum,
    temperatures, pressure and sound over Web Bluetooth (USB via Web Serial).
    Installable as a home-screen app and usable offline after first visit.
2026-10-01 Add firmware and enclosure design; move dashboard to app/
    - firmware/MANTIS: Nano 33 BLE Sense Rev1 firmware (ISO 10816 vibration
    analysis, PDM sound level, HTS221/LPS22HB, optional MLX90614 and piezo;
    BLE + USB JSON output)
    - mantis_enclosure.scad + stl/ + preview/: parametric FDM enclosure
    - Dashboard moved under app/ and deployed to Pages by a workflow
    - Root README with hardware list, build and printing notes
    [MANTIS_bottom_shell.stl, MANTIS_top_shell.stl, mantis_enclosure.scad]
2026-10-01 Fix sound level reading; help when MANTIS doesn't appear over BLE
    Firmware 1.1.0: the microphone signal is 80-90% sub-60 Hz drift, which the
    per-block mean removal left in, so the level sat near -55 dBFS whatever
    the sound. It now goes through an A-weighting filter (two biquads, matches
    IEC 61672 within 0.2 dB from 20 Hz to 2 kHz) and is reported in dB(A),
    calibrated from the MP34DT05 and nRF52840 PDM datasheets. Adds a USB "M"
    command that dumps raw mic samples for diagnostics.
    Dashboard: shows dB(A) with a quiet/normal/loud/hearing-hazard label, and
    when the Bluetooth chooser closes without a device it explains the usual
    causes (phone Bluetooth settings, Android location/nearby-devices
    pe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
    [MANTIS.ino]
2026-10-03 Turn the dashboard into an inspection app
    Layout
    - Four sections: Live, Analysis, Machines, Device. Bottom tab bar on
    phones, tabs under the header on computers.
    - Sticky header with the live zone and velocity, a dashed "demo" badge
    instead of the toast that covered the page, and one connect button.
    - Cleaner welcome card, IBM Plex Sans Arabic (cached for offline use),
    bottom-sheet dialogs on phones, spectrum axis labels no longer collide.
    Inspection workflow
    - Machines with name, location, ISO class and RPM, stored in the browser.
    - "Record measurement" saves a 10/15/30 s steady average (velocity,
    averaged spectrum, temperatures, sound) with an optional note.
    - Each machine is comp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
